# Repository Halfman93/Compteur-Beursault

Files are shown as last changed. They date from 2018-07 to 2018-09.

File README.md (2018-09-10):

# Compteur-Beursault
Système de comptage de point pour un jeu d'arc

Le système est fonctionnel. Il est basé sur des arduino nano pour des raisons de cout, les cartes acheté sur ebay coutant moins chers que les composants individuellement. 

Les PCB réalisés peuvent etre repris/Modifié à volonté. Au besoin ils peuvent etre commandé directement sur ce site : https://dirtypcbs.com/store/designer/browse/5639
Attention, en cas de livraison UPS des frais de douanes seront ajoutés. 

Le compteur est nommé scoreur.
Les 2 autres cartes à savoir télécommande et recepteur sont pour la partie radio. 

Une télécommande sans fil avec un recepteur (en 433MHz) est en cours de test. Les schématiques et logiciels sont déjà disponible. La documentation complète sera terminée lorsque le système sera qualifié. 

Have fun !

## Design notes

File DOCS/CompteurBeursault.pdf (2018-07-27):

# Compteur Beursault

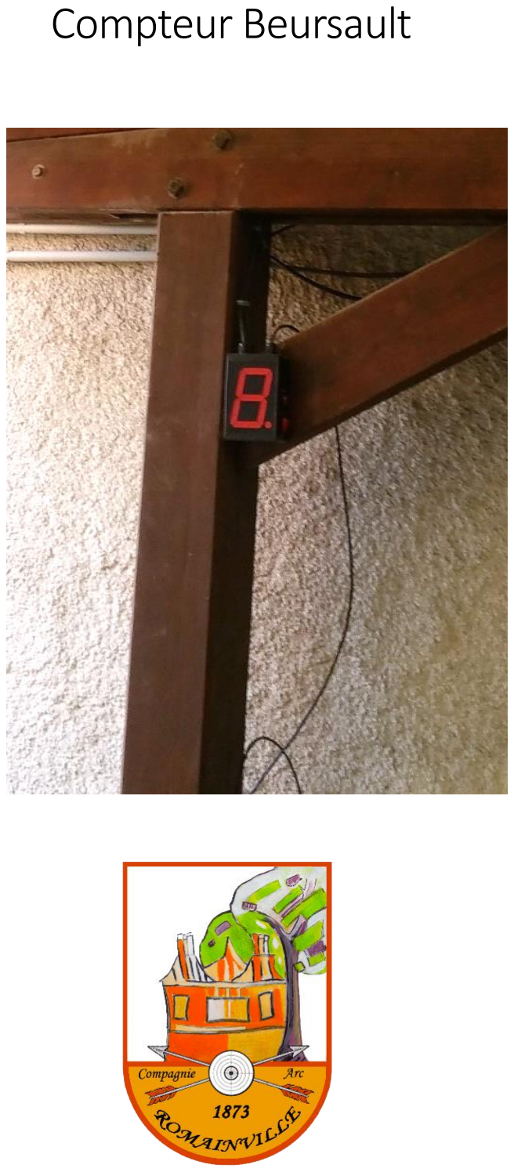
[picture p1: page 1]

# Carte contrôleur

## Matériel nécessaire

### - Arduino nano - PCB d’interface (fabrication Antoine) - Résistance de 10k CMS 0804

## Fabrication

Souder les résistances qui seront présente sous la carte Arduino.

Souder la carte Arduino sur le PCB d’interface. Le connecteur USB se trouve au niveau des pads de

### soudure pour la carte Sparkfun (donc à l’opposé du connecteur 12V !)

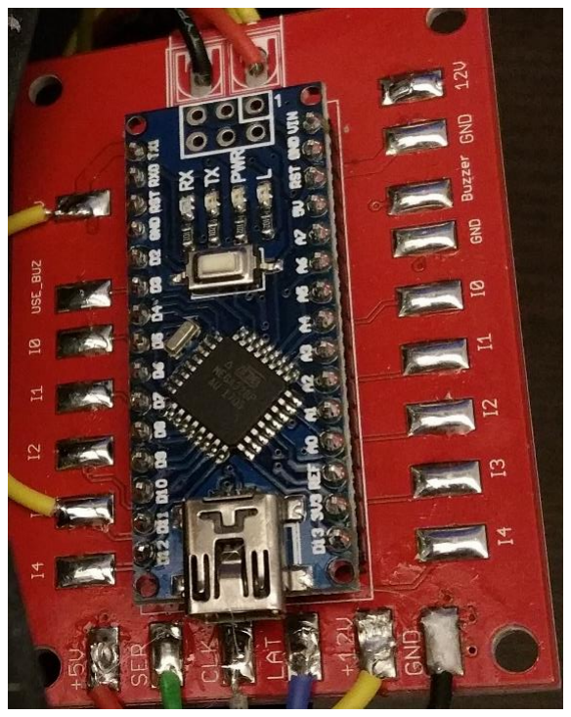
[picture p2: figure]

Étamer les différents plots de soudure pour faciliter le travail futur (et protéger les pads)

Flasher le code sur la carte Arduino grâce au connecteur USB. Celui-ci est présent en annexe au besoin.

# Afficheur

## Matériel nécessaire

- Boitier plastique (ou autre) : 150x100x55mm minimum afin de pouvoir tout faire rentrer dedans → 8€ environ fdpin - Afficheur 7 segment 12V : par exemple le CM1-4002LR00-W (disponible sur ebay en cherchant « big 7 segment ») → 10€ environ fdpin - Drivers 7 segment 12V (Sparkfun): Breakout Board TPIC6C596 (disponible sur ebay en cherchant “7 segment driver 12v”) → 2.18€ - Convertisseur 220V 12V (alimentation de LED) 12w min → 5€ - Prise Molex 6 points (et sa pince à sertir)

## Fabrication

Découper le boitier plastique afin de faire ressortir l’afficheur 7 segments. Fixer l’afficheur avec de la colle chaude afin d’assurer un minimum d’étanchéité. Une fois ceci fait, coller le driver 7 segment au dos de l’afficheur, les pads de soudure vers le bas de l’afficheur (le point est vers le bas )

Utiliser des fils silicone afin d’éviter toute cassure sur le long terme. Dénuder et souder les fils sur le boitier. Protéger les soudures avec de la gaine thermo rétractable. Une fois tous les fils parfaitement préparés, souder les fils au drivers Sparkfun en suivant ce câblage (la datasheet est en annexe).

### Câblage 7 segment (Le 1 est en bas à droite et le 6 en haut à gauche) :

1. 12v
2. E
3. D
4. C
5. DP
6. B
7. A
8. 12v
9. F
10. G

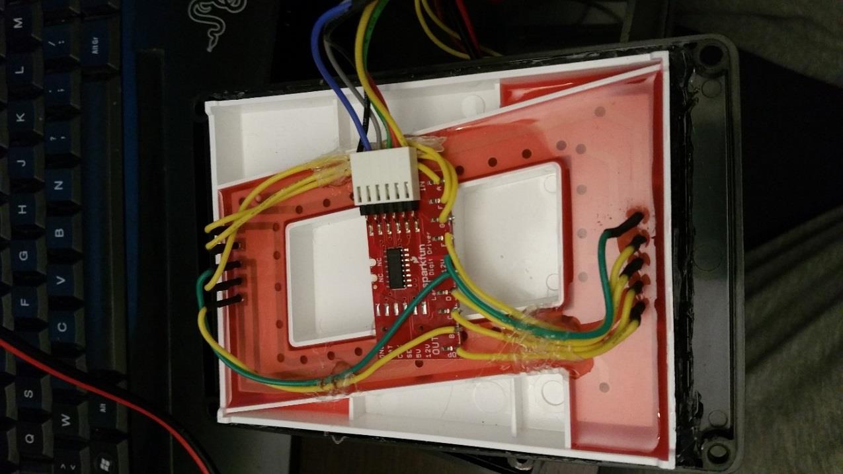
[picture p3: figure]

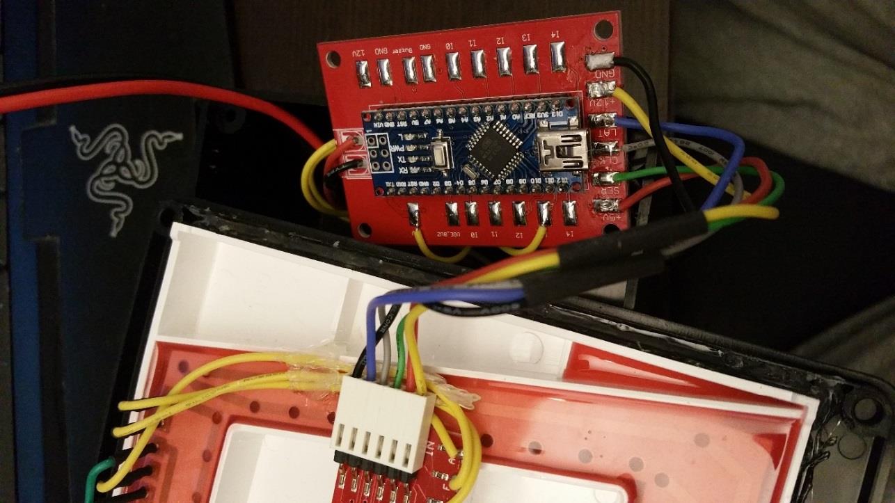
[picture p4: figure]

Dessouder le connecteur OUT de la carte Sparkfun pour éviter tout faux contact.

### Câblage Connecteur de la carte Drivers LED (Sparkfun) :

### 1. GND 2. LAT 3. CLK

### 4. SER

5. +5V
6. +12V

# Télécommande

## Matériel nécessaire

### - Boitier plastique aux dimensions : 129X40X25.5MM (disponible sur ebay en cherchant « boitier long noir 129 ») → 15€ fdpin - 5 boutons anti-vandalisme 16mm (disponible sur ebay en cherchant « 16mm anti vandal ») → 12€ fdpin

## Fabrication

### Pour placer 5 boutons à distance équivalentes, il faut faire un 1

### er trou à 11.5mm du tour intérieur puis tous les autres espacés de 23 mm

### Trous de 16mm de diamètre pour bouton anti vandalisme

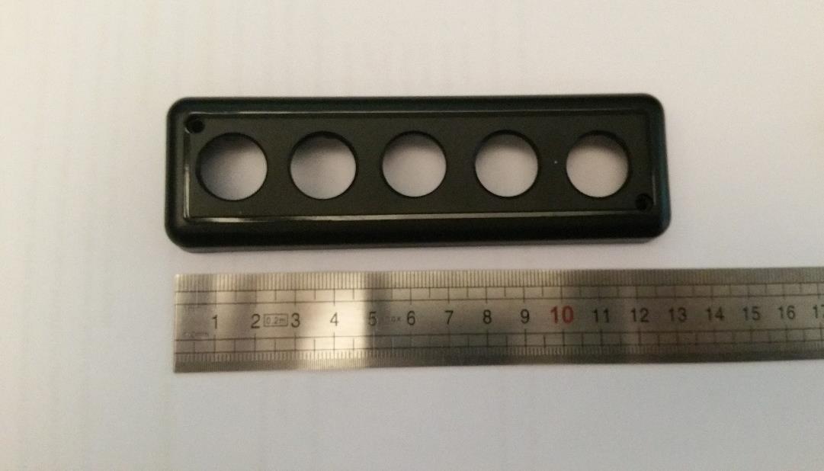
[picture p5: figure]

### Avec un bouton

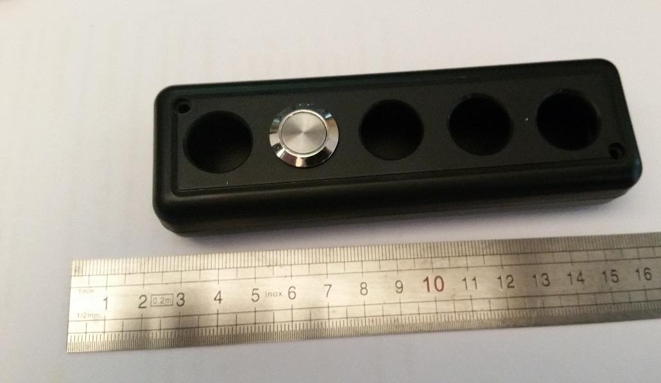
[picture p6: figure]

Pour les boutons, toutes les pattes d’un même coté sont relié au 5V. Les autres en fonction de leurs positions. Afin d’éviter tout soucis dans le temps, ne pas hésiter à souder les câbles aux connecteurs à vis. De toute façon il n’y a aucune raison pour réutiliser ces boutons (Attention à ne souder qu’une

### fois tout le câblage vérifié !)

# Câblage

## Matériel nécessaire

Câble réseau de 100m (ou 75m si disponible) permettant d’espacer 2 compteur de 50m ou plus et

### d’utiliser le reste pour câbler les télécommandes

## Fabrication

Câblage du câble Ethernet pour relier 2 boitier ensemble ou le boitier avec sa télécommande :

### Blanc/Orange : 5V Orange : 12V Bleu : 0 Blanc/Bleu : 1 Vert : 2 Blanc/Vert : 3 Blanc/Marron : 4 Marron : GND

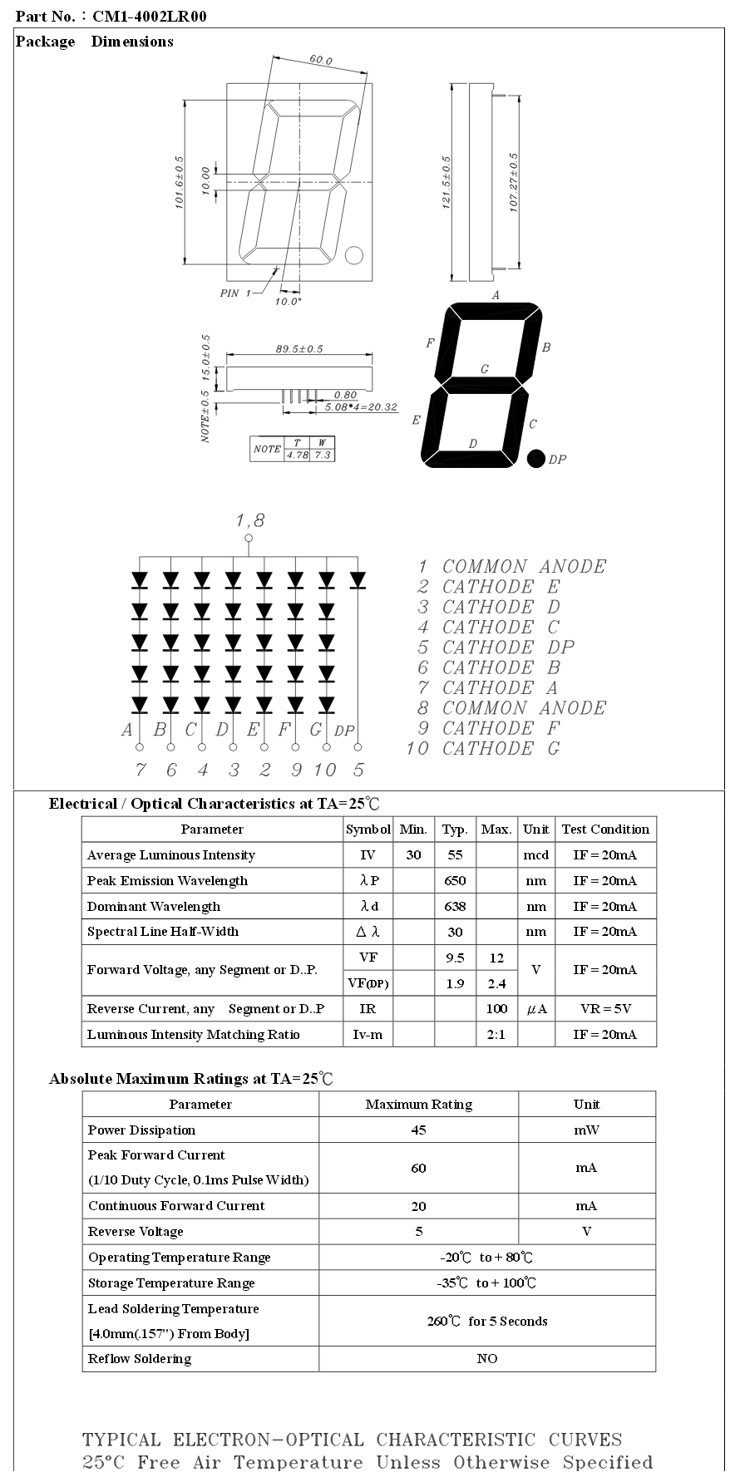
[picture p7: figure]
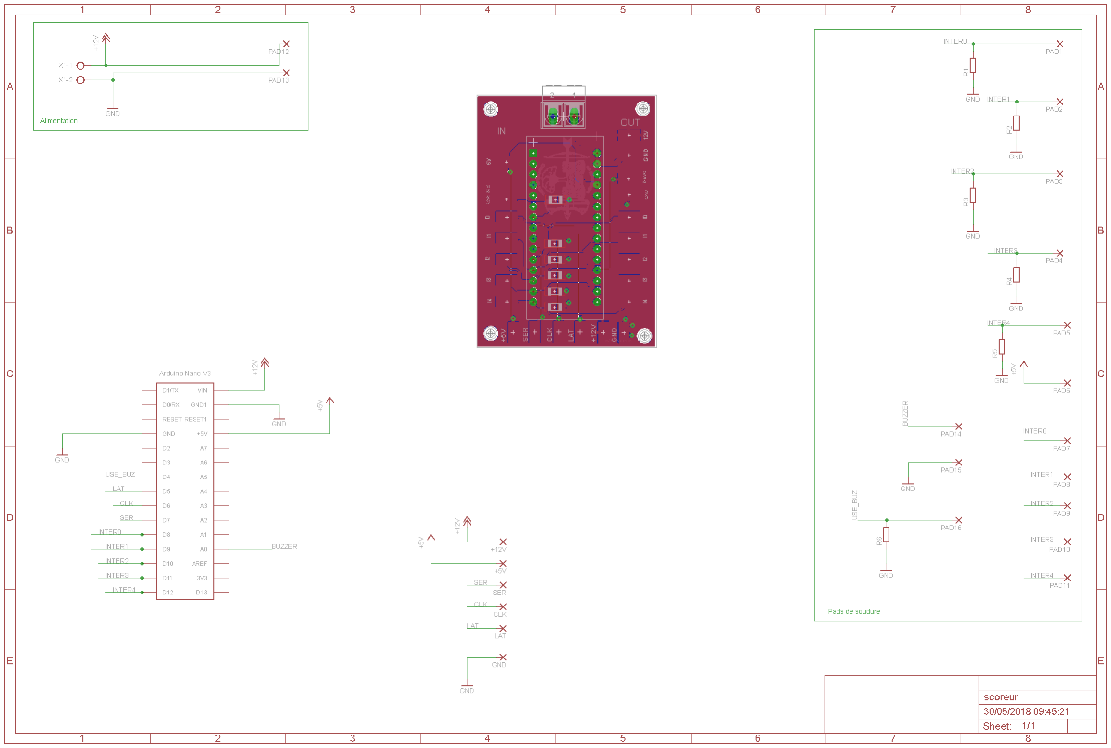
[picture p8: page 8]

# CODE ARDUINO

//GPIO declarations
//-=-=-=-=-=-=-=-=-=-=-=-=-=-=-=-=-=-=-=-=-=-=-=-= byte segmentClock = 6;
byte segmentLatch = 5;
byte segmentData = 7;
byte btn0 = 8;
byte btn1 = 9;
byte btn2 = 10;
byte btn3 = 11;
byte btn4 = 12;
byte btnBuzz = 4;
byte buzzer = A0;
//-=-=-=-=-=-=-=-=-=-=-=-=-=-=-=-=-=-=-=-=-=-=-=-=

int currentScore = 9;
unsigned long time = 0;
#define MAX_TIME_AFFICHE 5*1000

void buzz(int nb)
{
if(digitalRead(btnBuzz) == HIGH)
{
for(int i=0;i<nb;i++)
{
digitalWrite(buzzer,HIGH); delay(500);
digitalWrite(buzzer,LOW);
delay(500);
}
}
}

void setup()
{
Serial.begin(9600);

pinMode(segmentClock, OUTPUT); pinMode(segmentData, OUTPUT); pinMode(segmentLatch, OUTPUT);

pinMode(btn0, INPUT);
pinMode(btn1, INPUT);
pinMode(btn2, INPUT);
pinMode(btn3, INPUT);
pinMode(btn4, INPUT);
pinMode(btnBuzz, INPUT);
pinMode(buzzer, OUTPUT);
digitalWrite(buzzer,LOW);

digitalWrite(segmentClock, LOW); digitalWrite(segmentData, LOW); digitalWrite(segmentLatch, LOW);

for(int i=4;i>=0;i--)
{
postNumber(i, false);
digitalWrite(segmentLatch, LOW);
digitalWrite(segmentLatch, HIGH); //Register moves storage register on the rising edge of RCK delay(500);
}
}

void loop()
{
byte needBuzz = 0;
if(digitalRead(btn0) == HIGH) {
time = millis();
currentScore = 0;
needBuzz = 1;
}
if(digitalRead(btn1) == HIGH) {
time = millis();
currentScore = 1;
needBuzz = 1;
}
if(digitalRead(btn2) == HIGH) {
time = millis();
currentScore = 2;
needBuzz = 1;
}
if(digitalRead(btn3) == HIGH) {
time = millis();
currentScore = 3;
needBuzz = 1;
}
if(digitalRead(btn4) == HIGH) {
time = millis();
currentScore = 4;
needBuzz = 1;
}

if(millis() < time+MAX_TIME_AFFICHE) {
if(currentScore <=4)
postNumber(currentScore, false); }
else
{
Serial.println("TimeMax");
for (byte x = 0 ; x < 8 ; x++)
{
digitalWrite(segmentClock, LOW);
digitalWrite(segmentData, 0);
digitalWrite(segmentClock, HIGH); //Data transfers to the register on the rising edge of SRCK }
}
digitalWrite(segmentLatch, LOW);
digitalWrite(segmentLatch, HIGH); //Register moves storage register on the rising edge of RCK

if(needBuzz == 1)
{
buzz(currentScore);
needBuzz = 0;
}

delay(10);
}

//Takes a number and displays 2 numbers. Displays absolute value (no negatives)

void showNumber(float value)
{
int number = abs(value); //Remove negative signs and any decimals

for (byte x = 0 ; x < 2 ; x++)
{
int remainder = number % 10;
postNumber(remainder, false); number /= 10;
}

//Latch the current segment data
digitalWrite(segmentLatch, LOW);
digitalWrite(segmentLatch, HIGH); //Register moves storage register on the rising edge of RCK }

//Given a number, or '-', shifts it out to the display
void postNumber(byte number, boolean decimal)
{
// - A
// / / F/B
// - G
// / / E/C
// -. D/DP

#define a 1<<0

#define b 1<<6

#define c 1<<5

#define d 1<<4

#define e 1<<3

#define f 1<<1

#define g 1<<2

#define dp 1<<7

byte segments;

switch (number)
{
case 1: segments = b | c; break;
case 2: segments = a | b | d | e | g; break;
case 3: segments = a | b | c | d | g; break;
case 4: segments = f | g | b | c; break;
case 5: segments = a | f | g | c | d; break;
case 6: segments = a | f | g | e | c | d; break;
case 7: segments = a | b | c; break;
case 8: segments = a | b | c | d | e | f | g; break;
case 9: segments = a | b | c | d | f | g; break;
case 0: segments = a | b | c | d | e | f; break;
case ' ': segments = 0; break;
case 'c': segments = g | e | d; break;
case '-': segments = g; break;
}

if (decimal) segments |= dp;
//Clock these bits out to the drivers for (byte x = 0 ; x < 8 ; x++)
{
digitalWrite(segmentClock, LOW);
digitalWrite(segmentData, segments & 1 << (7 - x));
digitalWrite(segmentClock, HIGH); //Data transfers to the register on the rising edge of SRCK }
}

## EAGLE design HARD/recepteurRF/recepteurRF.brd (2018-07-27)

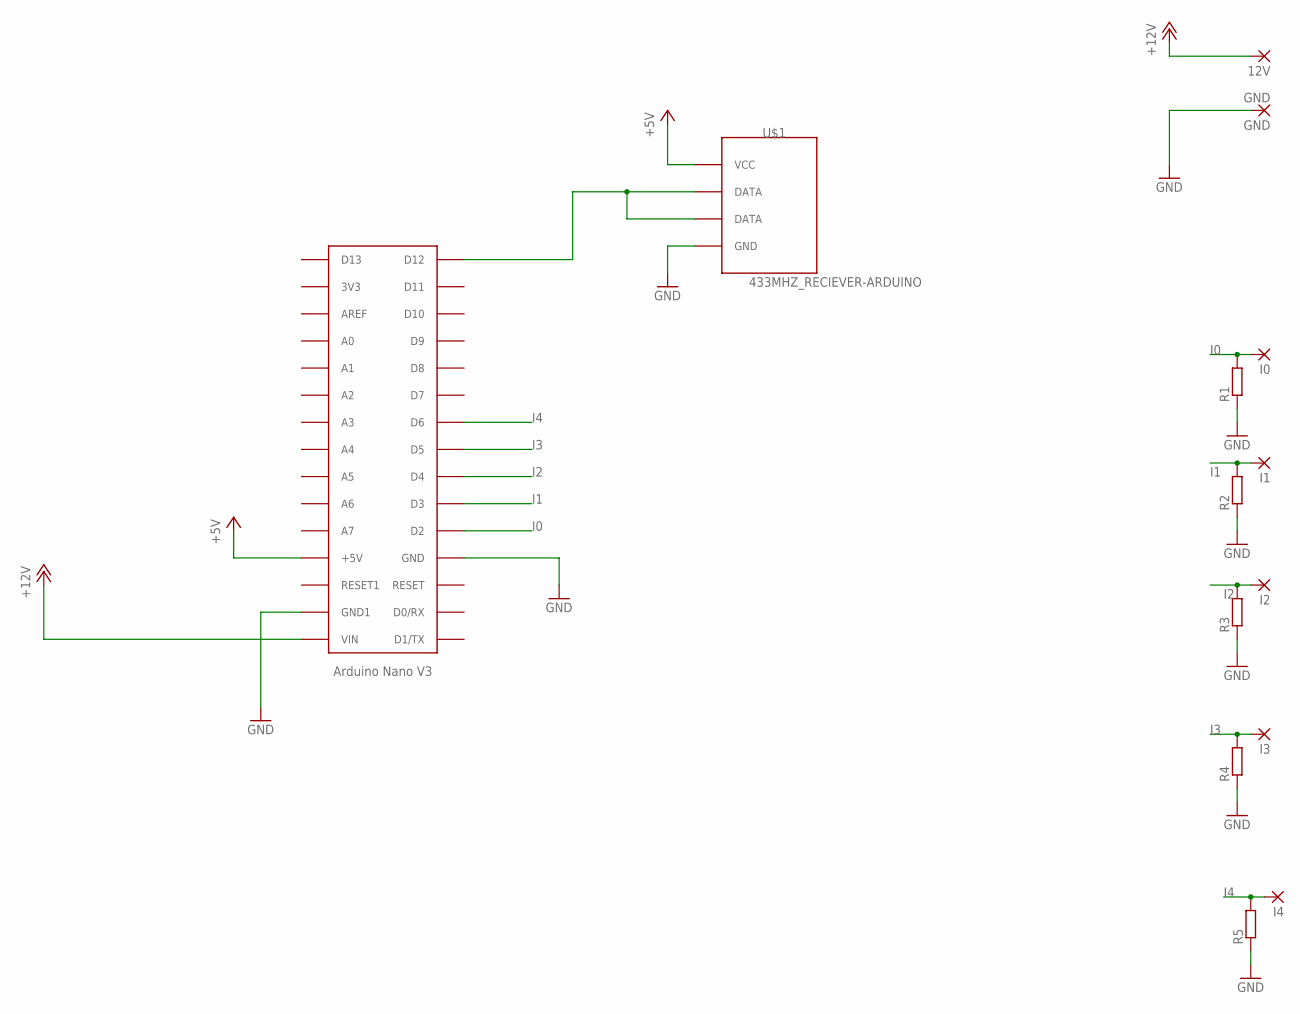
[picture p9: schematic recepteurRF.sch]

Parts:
12V: SMD5; SMD2,54-5,08
GND: GND; SMD2,54-5,08
I0, I1, I2, I3, I4: SMD5; SMD2,54-5,08
R1, R2, R3, R4, R5: R-EU_R1206; R1206
U$1: 433MHZ_RECIEVER-ARDUINO
U$2: ARDUINONANO; PDIP-32

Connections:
+5V: U$1.VCC, U$2.+5V
+12V: 12V.1, U$2.VIN
GND: GND.1, R1.1, R2.1, R3.1, R4.1, R5.1, U$1.GND, U$2.GND, U$2.GND1
I0: I0.1, R1.2, U$2.D2
I1: I1.1, R2.2, U$2.D3
I2: I2.1, R3.2, U$2.D4
I3: I3.1, R4.2, U$2.D5
I4: I4.1, R5.2, U$2.D6
unnamed: U$1.DATA@0 (DATA), U$1.DATA@1 (DATA), U$2.D12

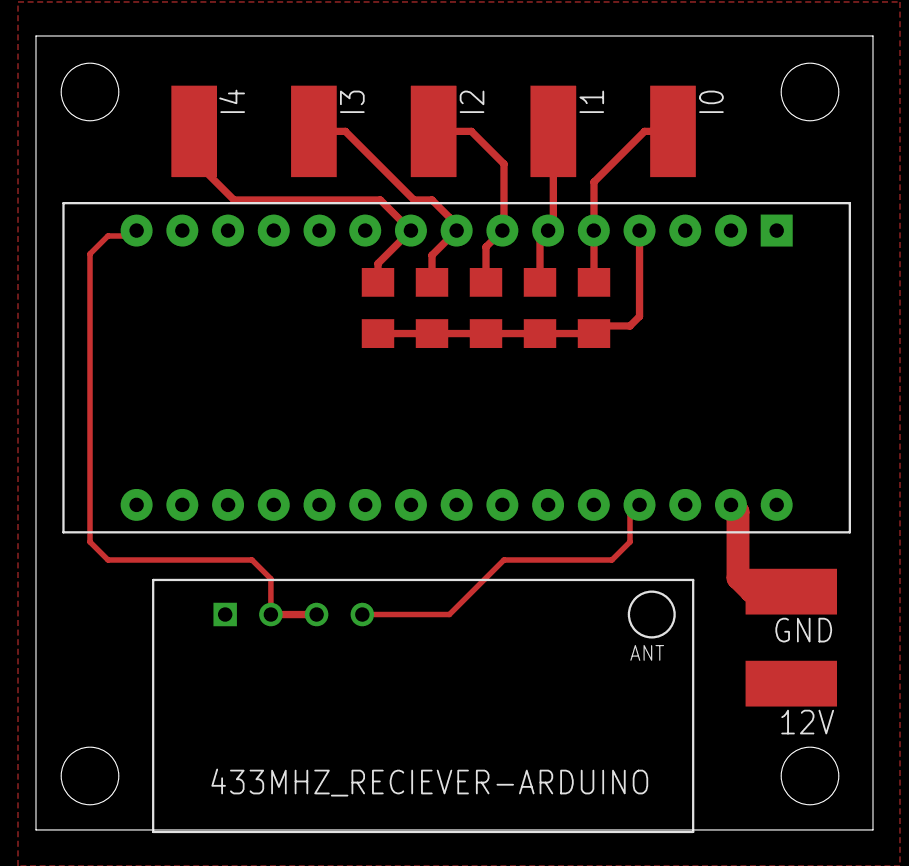
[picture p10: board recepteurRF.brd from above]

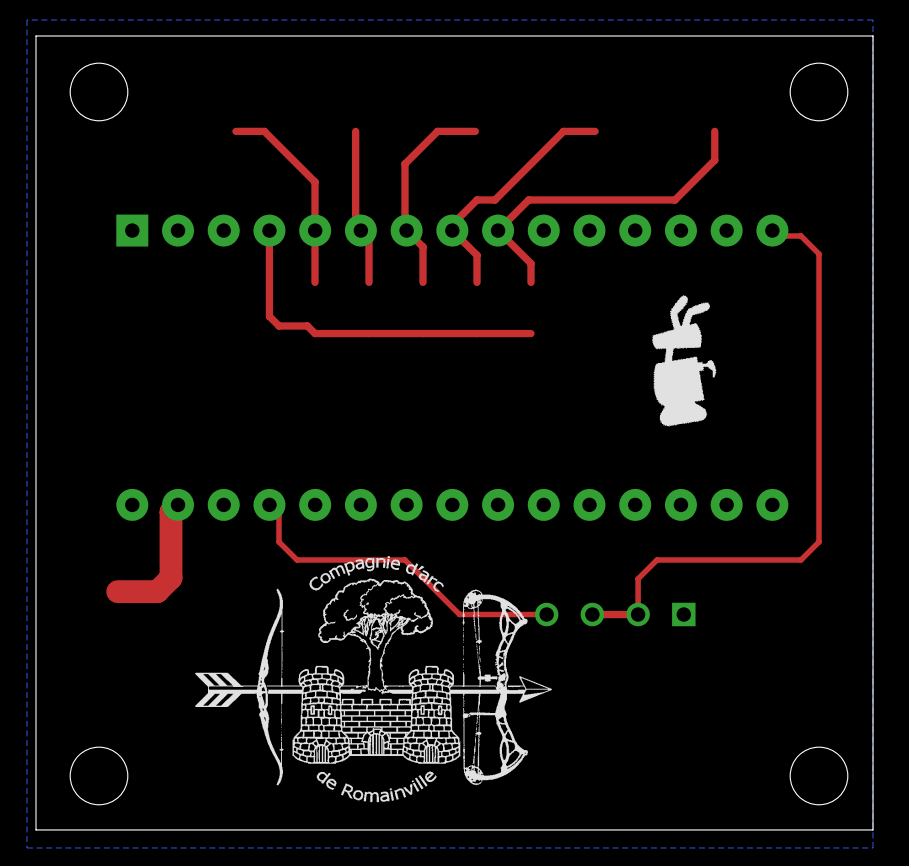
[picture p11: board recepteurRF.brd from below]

Board: 2 copper layers, 46.5 x 44.1 mm, 16 parts (2 on the bottom side), 9 nets.

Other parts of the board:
U$3: LOGO
U$4: LOGO_GROS

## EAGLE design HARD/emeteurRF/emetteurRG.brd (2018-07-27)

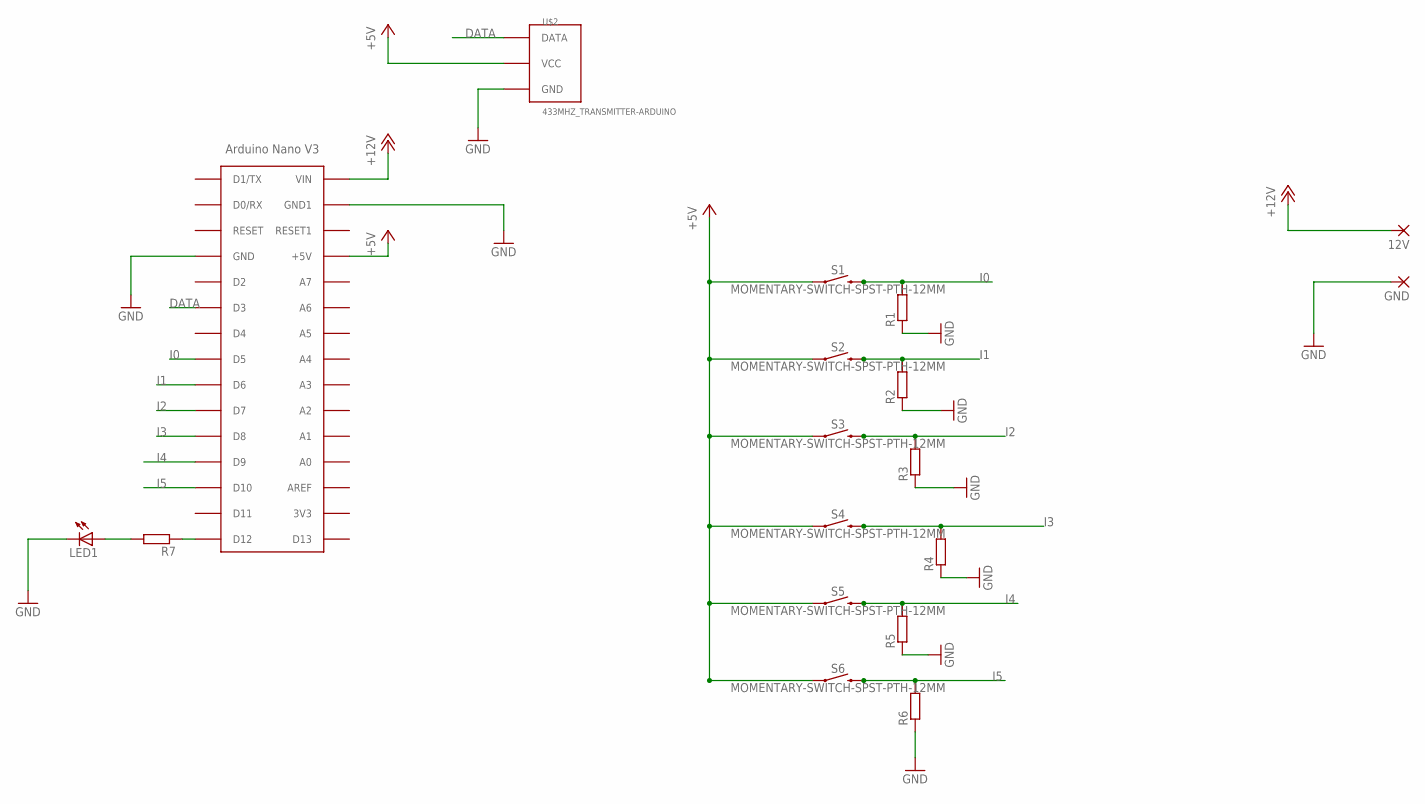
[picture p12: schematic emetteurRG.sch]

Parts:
12V: SMD5; SMD2,54-5,08
GND: SMD5; SMD2,54-5,08
LED1: LED5MM
R1, R2, R3, R4, R5, R6, R7: R-EU_R1206; R1206
S1, S2, S3, S4, S5, S6: MOMENTARY-SWITCH-SPST-PTH-12MM; TACTILE_SWITCH_PTH_12MM
U$1: ARDUINONANO; PDIP-32
U$2: 433MHZ_TRANSMITTER-ARDUINO

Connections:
+5V: S1.1, S2.1, S3.1, S4.1, S5.1, S6.1, U$1.+5V, U$2.VCC
+12V: 12V.1, U$1.VIN
DATA: U$1.D3, U$2.DATA
GND: GND.1, LED1.K (C), R1.1, R2.1, R3.1, R4.1, R5.1, R6.1, U$1.GND, U$1.GND1, U$2.GND
I0: R1.2, S1.3 (2), U$1.D5
I1: R2.2, S2.3 (2), U$1.D6
I2: R3.2, S3.3 (2), U$1.D7
I3: R4.2, S4.3 (2), U$1.D8
I4: R5.2, S5.3 (2), U$1.D9
I5: R6.2, S6.3 (2), U$1.D10
unnamed: LED1.A, R7.2
unnamed: R7.1, U$1.D12

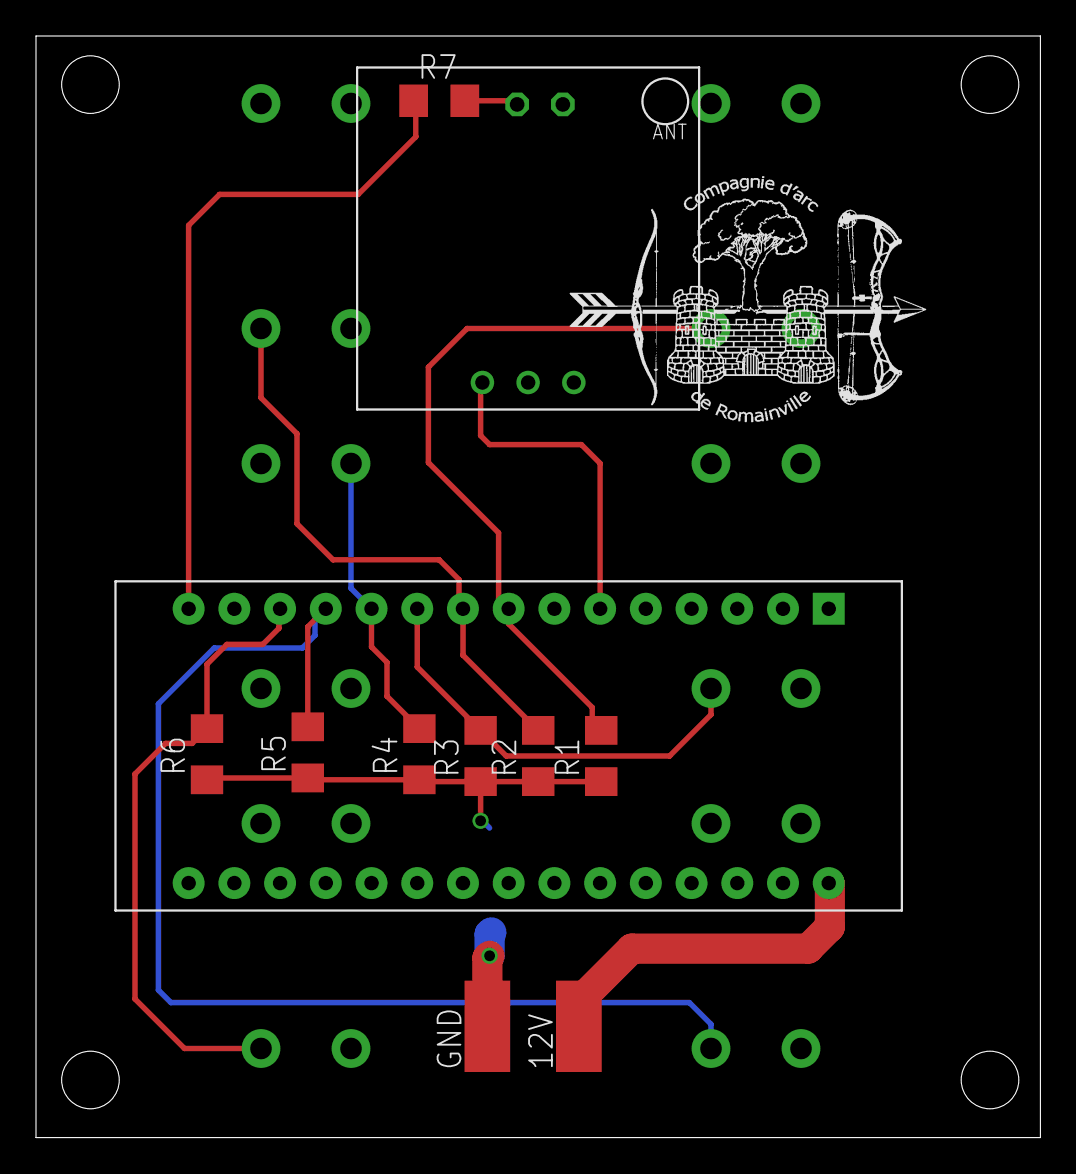
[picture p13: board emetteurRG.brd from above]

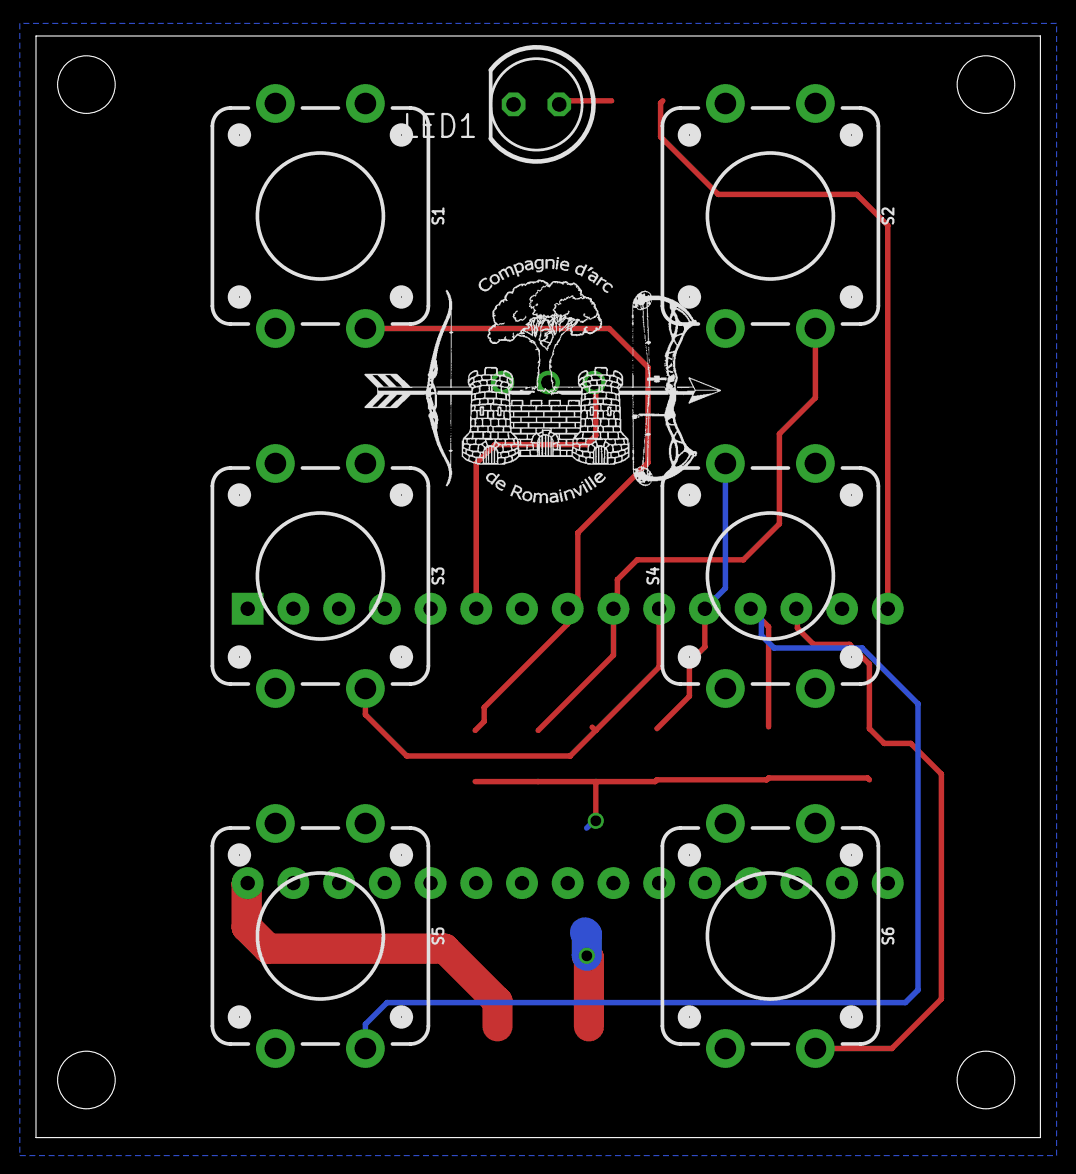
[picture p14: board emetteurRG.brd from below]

Board: 2 copper layers, 55.8 x 61.2 mm, 20 parts (8 on the bottom side), 12 nets.

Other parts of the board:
U$3, U$4: LOGO

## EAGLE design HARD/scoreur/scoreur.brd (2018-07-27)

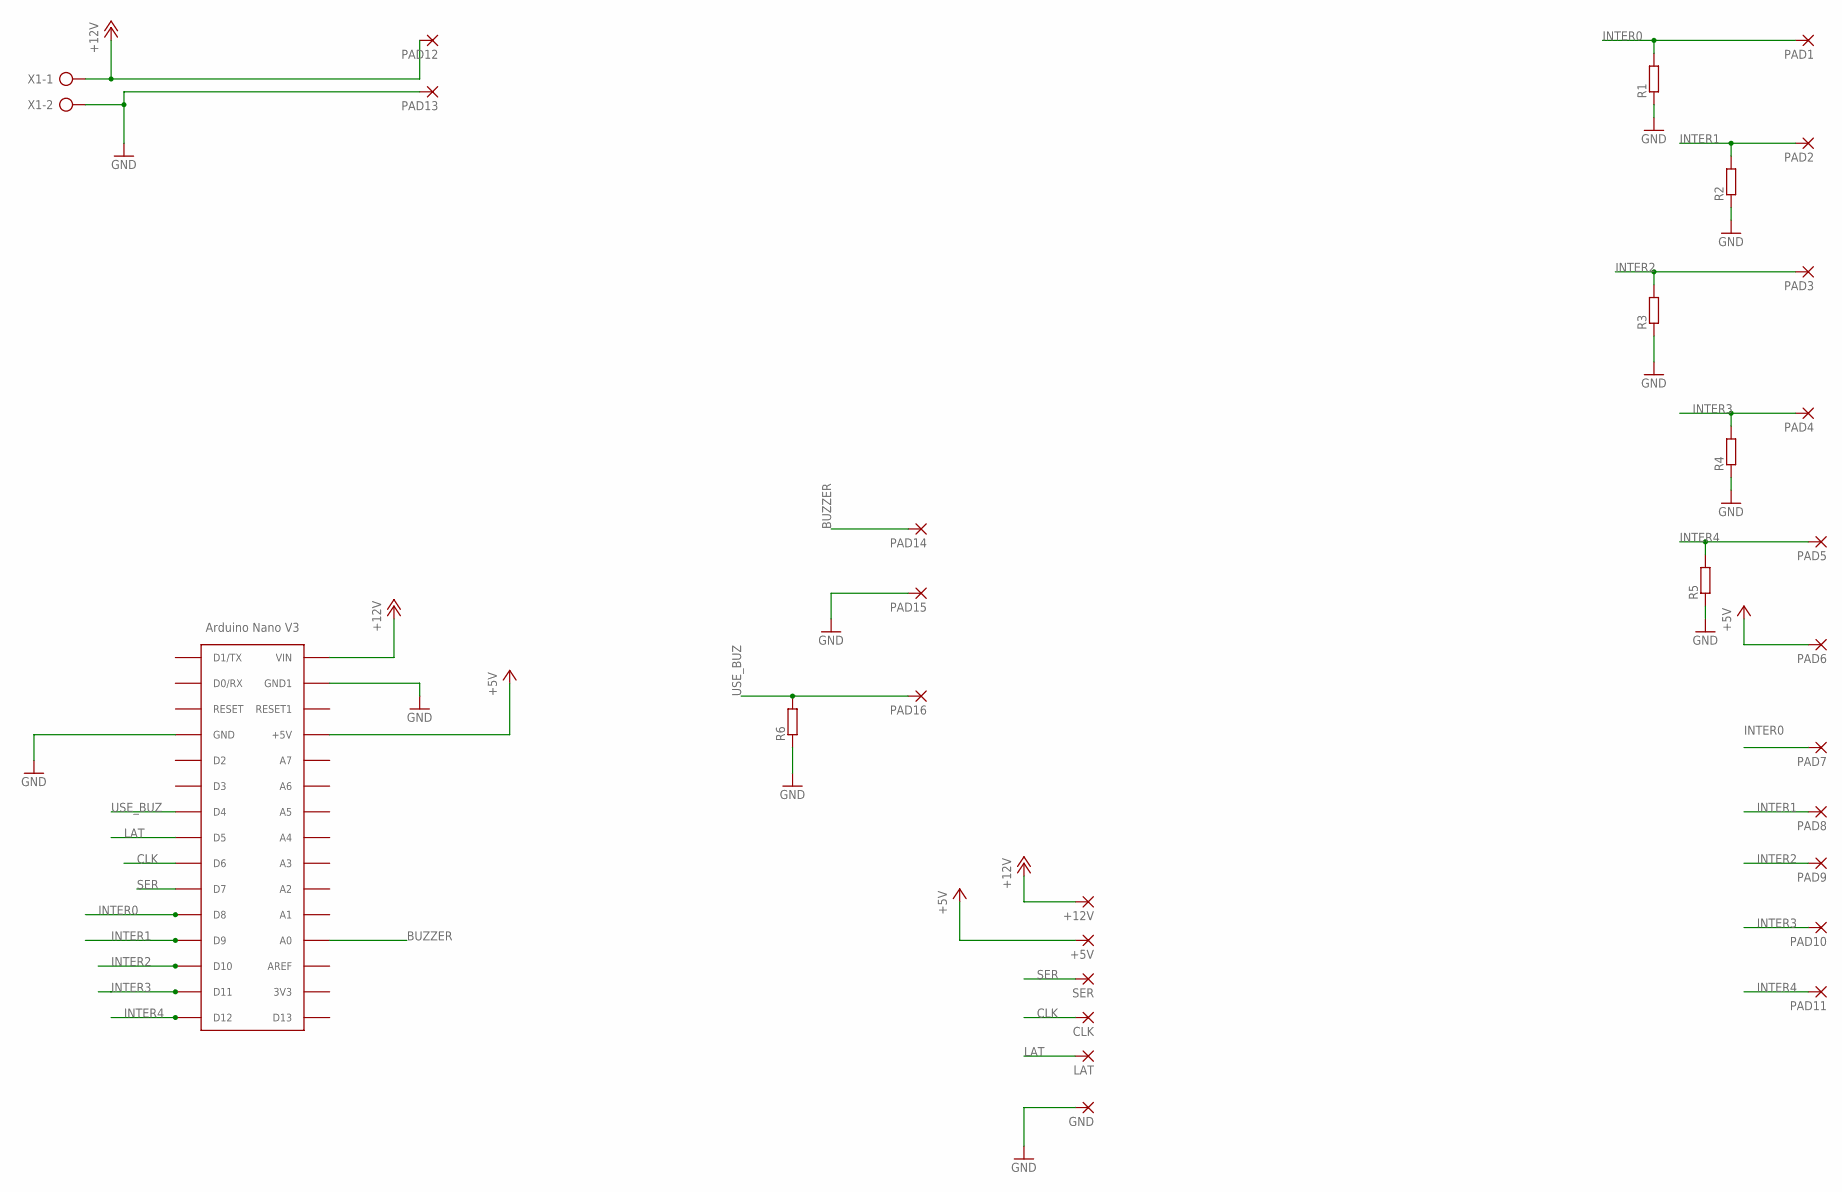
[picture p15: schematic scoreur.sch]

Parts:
+5V, +12V: SMD5; SMD2,54-5,08
CLK: SMD5; SMD2,54-5,08
GND: SMD5; SMD2,54-5,08
LAT: SMD5; SMD2,54-5,08
PAD1, PAD2, PAD3, PAD4, PAD5, PAD6, PAD7, PAD8, PAD9, PAD10, PAD11, PAD12, PAD13, PAD14, PAD15, PAD16: SMD5; SMD2,54-5,08
R1, R2, R3, R4, R5, R6: R-EU_R1206; R1206
SER: SMD5; SMD2,54-5,08
U$1: ARDUINONANO; PDIP-32
X1: AK500/2-H

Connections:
+5V: +5V.1, PAD6.1, U$1.+5V
+12V: +12V.1, PAD12.1, U$1.VIN, X1.1
BUZZER: PAD14.1, U$1.A7 (A0)
CLK: CLK.1, U$1.D6
GND: GND.1, PAD13.1, PAD15.1, R1.1, R2.1, R3.1, R4.1, R5.1, R6.1, U$1.GND, U$1.GND1, X1.2
INTER0: PAD1.1, PAD7.1, R1.2, U$1.D8
INTER1: PAD2.1, PAD8.1, R2.2, U$1.D9
INTER2: PAD3.1, PAD9.1, R3.2, U$1.D10
INTER3: PAD4.1, PAD10.1, R4.2, U$1.D11
INTER4: PAD5.1, PAD11.1, R5.2, U$1.D12
LAT: LAT.1, U$1.D5
SER: SER.1, U$1.D7
USE_BUZ: PAD16.1, R6.2, U$1.D4

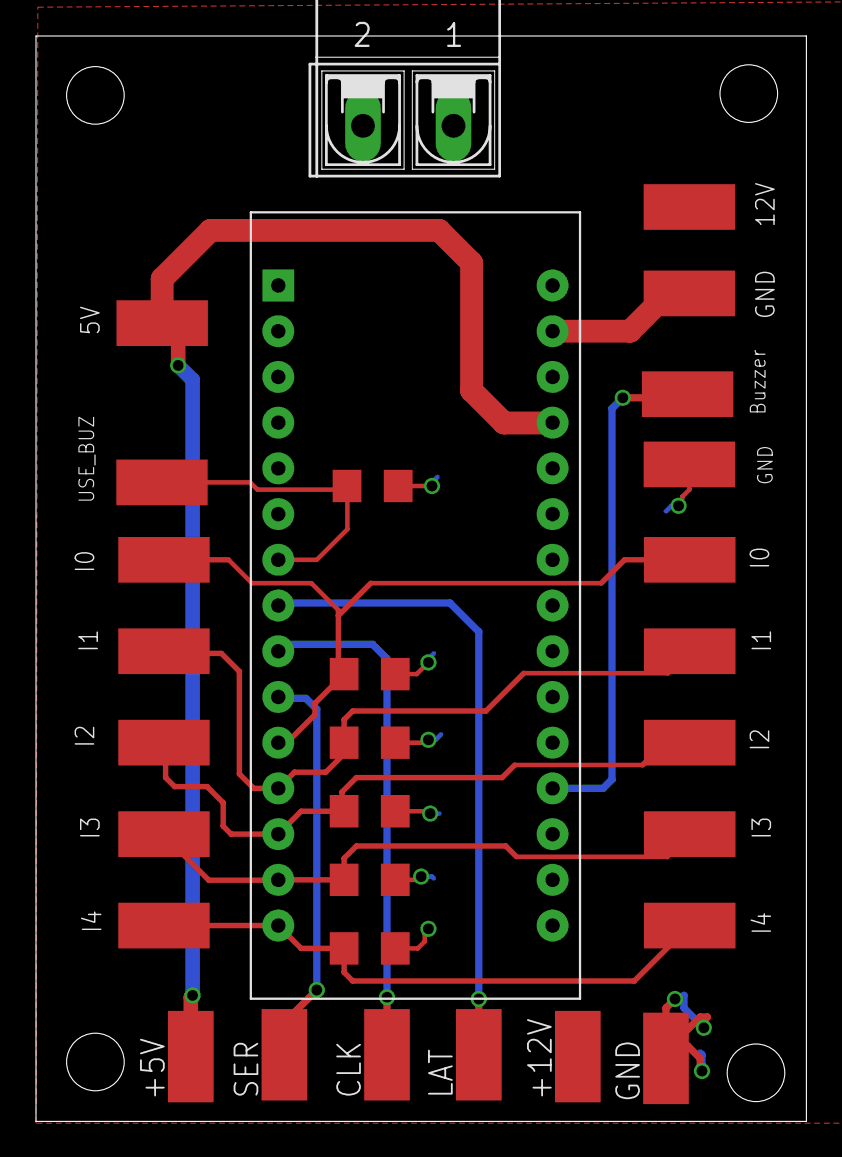
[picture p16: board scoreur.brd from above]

Board: 2 copper layers, 42.8 x 60.3 mm, 31 parts (1 on the bottom side), 13 nets.

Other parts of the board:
U$2: LOGO

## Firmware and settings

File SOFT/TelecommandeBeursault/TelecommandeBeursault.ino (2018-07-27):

#include <VirtualWire.h>

byte btn0 = 5;
byte btn1 = 6;
byte btn2 = 7;
byte btn3 = 8;
byte btn4 = 9;
byte btnNo = 10;
byte led = 12;

void setup()
{
  pinMode(btn0, INPUT);
  pinMode(btn1, INPUT);
  pinMode(btn2, INPUT);
  pinMode(btn3, INPUT);
  pinMode(btn4, INPUT);
  pinMode(btnNo, INPUT);

  pinMode(led, OUTPUT);

  Serial.begin(9600);

  vw_set_tx_pin(3);
  vw_setup(2000); // initialisation de la bibliothèque VirtualWire à 2000 bauds
  
}

void Send(int value)
{
  Serial.println(value); 
  digitalWrite(led,HIGH);
  byte message[2];
  memcpy(message, &value, sizeof(value));
  vw_send(message,2);
  vw_wait_tx();
  delay(400);
  digitalWrite(led,LOW);
  
}
void loop() 
{
   if(digitalRead(btn0) == HIGH)
    {
      Send(0);
    }
    if(digitalRead(btn1) == HIGH)
    {
      Send(1);
    }
    if(digitalRead(btn2) == HIGH)
    {
      Send(2);
    }
    if(digitalRead(btn3) == HIGH)
    {
      Send(3);
    }
    if(digitalRead(btn4) == HIGH)
    {
      Send(4);
    }
    if(digitalRead(btnNo) == HIGH)
    {
      Send(5);
    }

}

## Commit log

2018-07-27 Premier commit
    [emetteurRG.brd, emetteurRG.sch, recepteurRF.brd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]
2018-09-10 Correction bug d'affichage en cas de doute. Affichage d'un tiret en cas de doute au lieu d'un nombre qui clignote. Plus visuel et compatible avec la version sans fil.
    [CompteurBeursault.ino]

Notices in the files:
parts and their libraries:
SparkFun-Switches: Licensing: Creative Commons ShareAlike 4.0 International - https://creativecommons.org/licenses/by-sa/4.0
